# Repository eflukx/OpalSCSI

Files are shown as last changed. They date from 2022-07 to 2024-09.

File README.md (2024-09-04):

# OpalSCSI

Nice, tidy and small BlueSCSI-compatible dongle made to fit classic Macintosh computers. (But probably fits a whole lot more machines sporting a DB-25 SCSI connector!)

## Background

I found an old Macintosh 512k lying around and obviously ~~wanted~~ needed to boot it. It did come with a (rather large) box containing a SCSI drive, but unfortunately/unsurprisingly it did not stand the test of time.. 🥹
So with no apparent way to be able to boot my Mac and no appetite to fiddle with old SCSI drives I stumbled upon the great BlueSCSI project! I loved the project and decided build some hardware to go with the firmware. The design for this is what you find in this repository.
I had all components needed and I did not want to fiddle with loose (dupont) wiring to a bluepill or SCSI cabling or whatever. Therefore decided to build a small dongle board that takes a SD-card and directly plugs into the computer.

## Some nice pictas

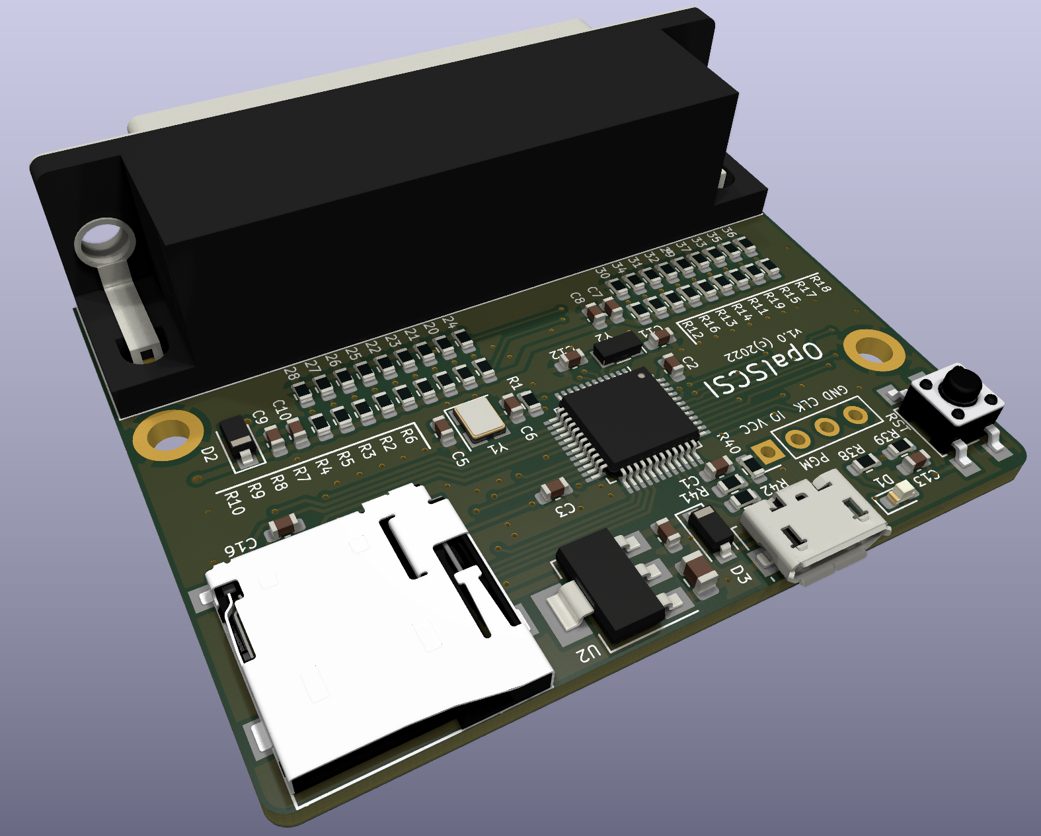
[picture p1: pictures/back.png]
PCB back

<!-- ![PCB bottom_flat](pictures/bottom_flat.png) -->
<!-- ![PCB bottom_perspective](pictures/bottom_perspective.png) -->
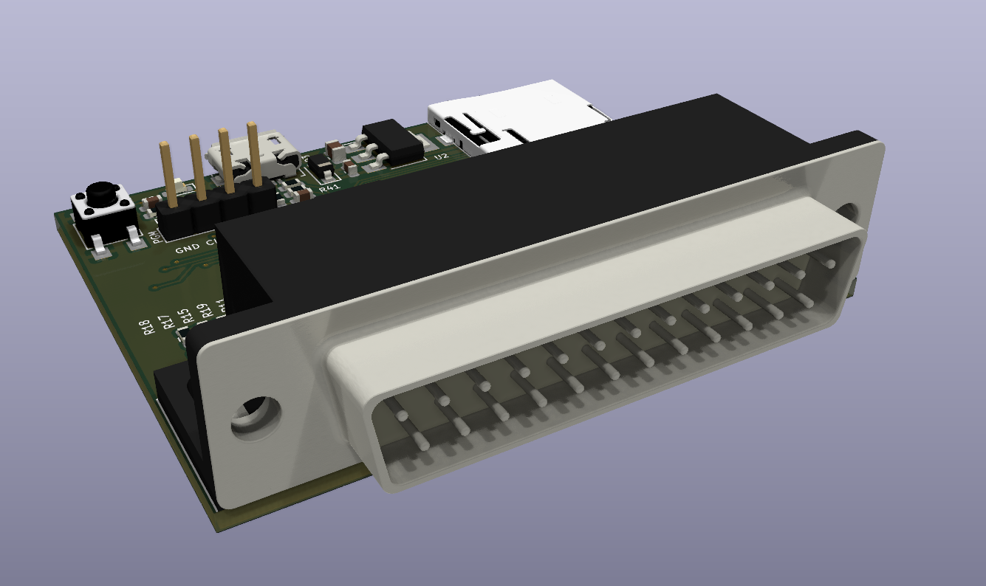
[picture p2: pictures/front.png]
PCB front

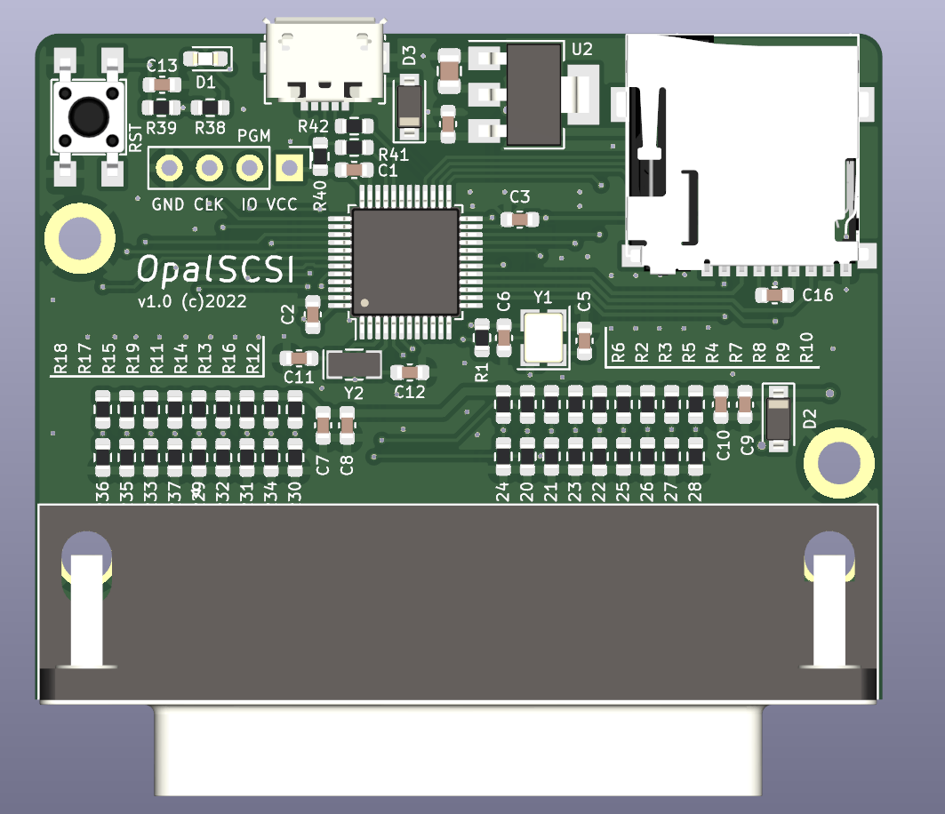
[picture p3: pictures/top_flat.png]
PCB top_flat


## Get one of my boards!

I've had some (5) boards produced and soldered 2 devices together for own use. As I still have some boards lying around, you can get one at shipping cost! 🥳 Just create an issue here with the request, I'll probably pick it up.. :)

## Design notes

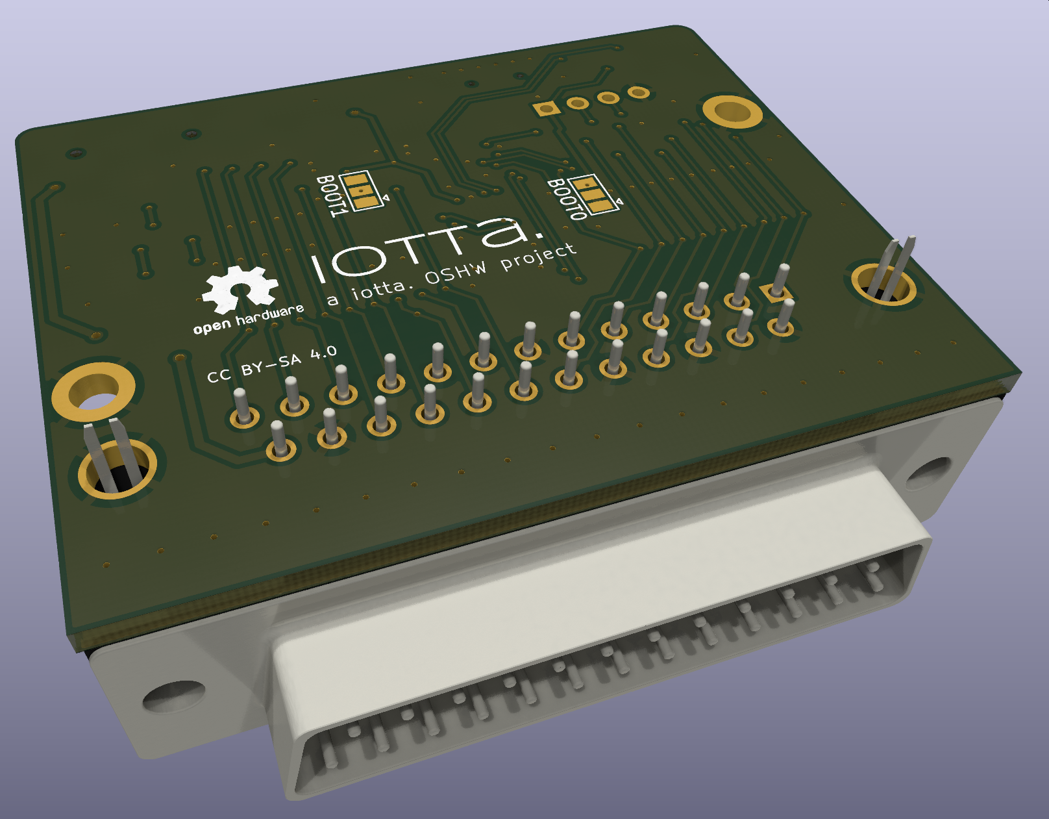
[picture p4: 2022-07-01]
pictures/bottom_perspective.png

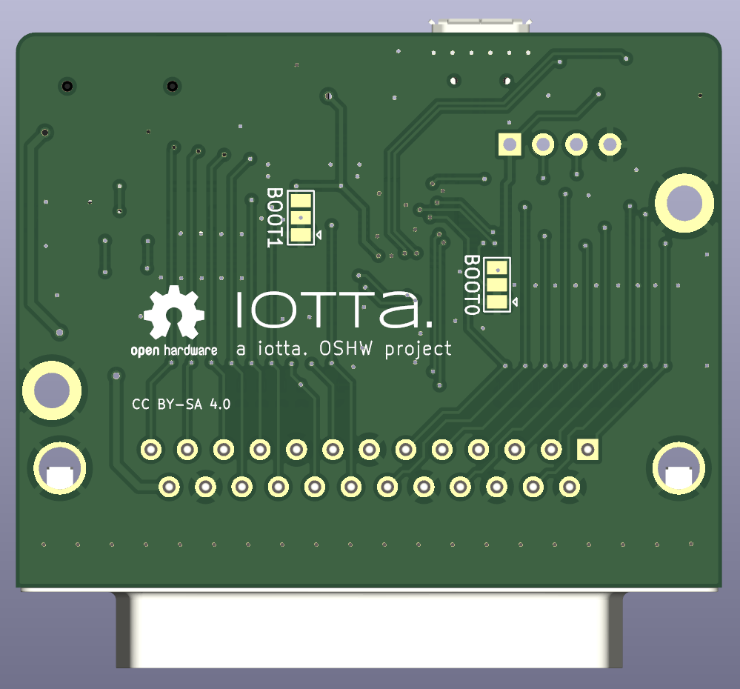
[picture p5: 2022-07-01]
pictures/bottom_flat.png

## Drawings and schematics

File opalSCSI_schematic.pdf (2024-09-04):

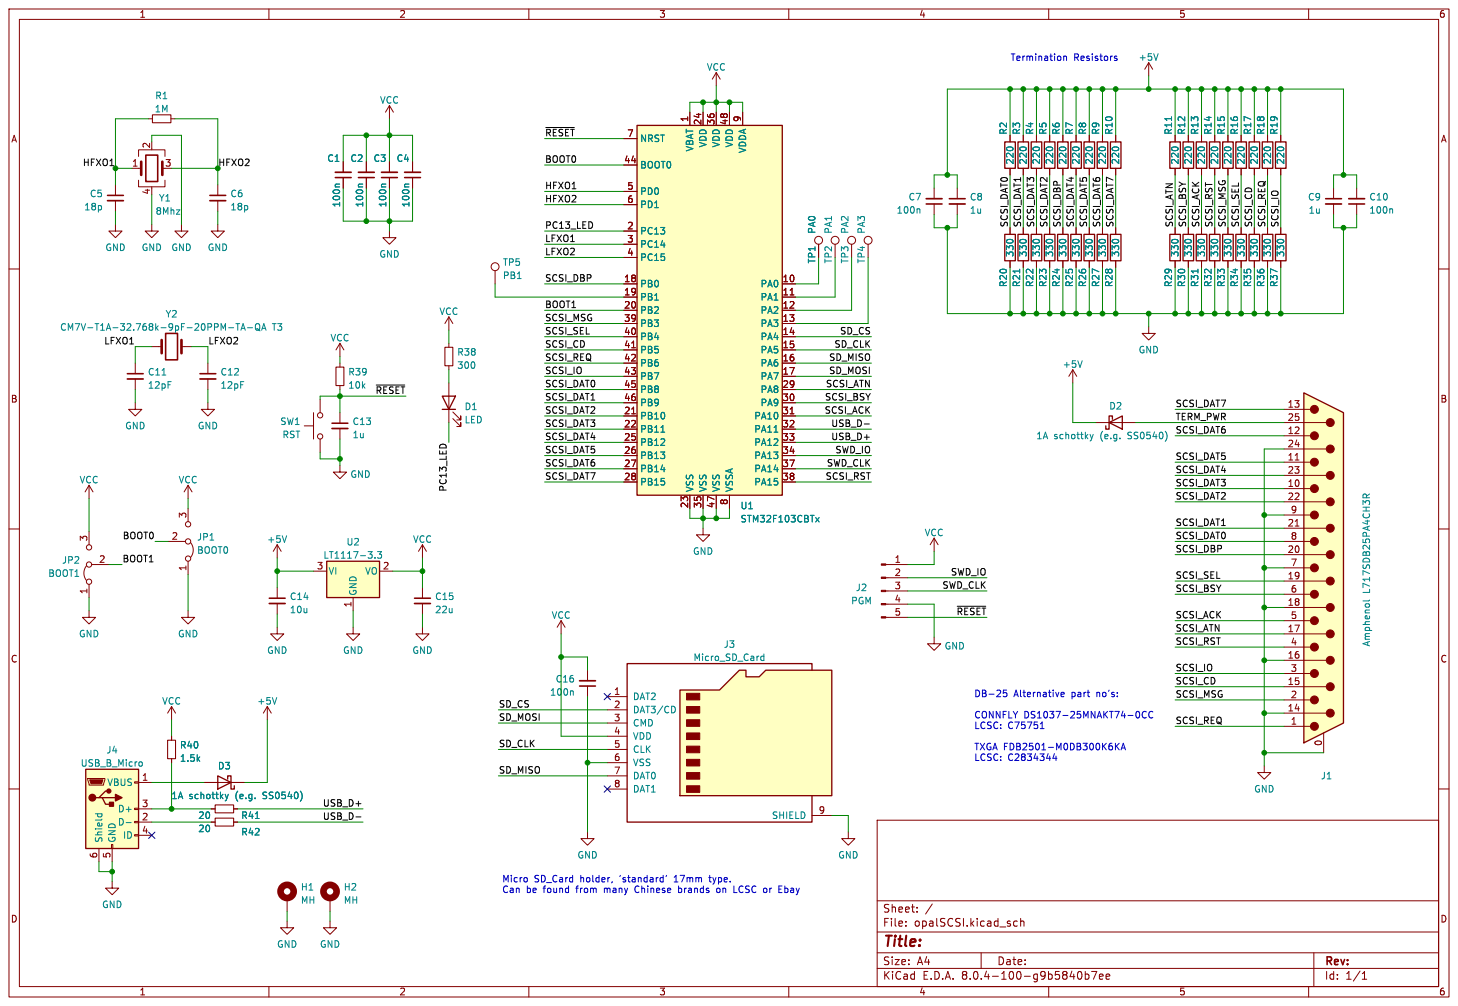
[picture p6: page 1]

1 PA0 10 PA1 11 PA2 12 PA3 13 PA4 14 PA5 15 PA6 16 PA7 17 PB0 18 PB1 19 PC13 2 PB2 20 PB10 21 PB11 22 VSS 23 VDD 24 PB12 25 PB13 26 PB14 27 PB15 28 PA8 29 PC14 3 PA9 30 PA10 31 PA11 32 PA12 33 PA13 34 VSS 35 VDD 36 PA14 37 PA15 38 PB3 39 PC15 4 PB4 40 PB5 41 PB6 42 PB7 43 BOOT0 44 PB8 45 PB9 46 VSS 47 VDD 48 PD0 5 PD1 6 NRST 7 VSSA

Id: 1/1 Title: File: opalSCSI.kicad_sch Sheet: /

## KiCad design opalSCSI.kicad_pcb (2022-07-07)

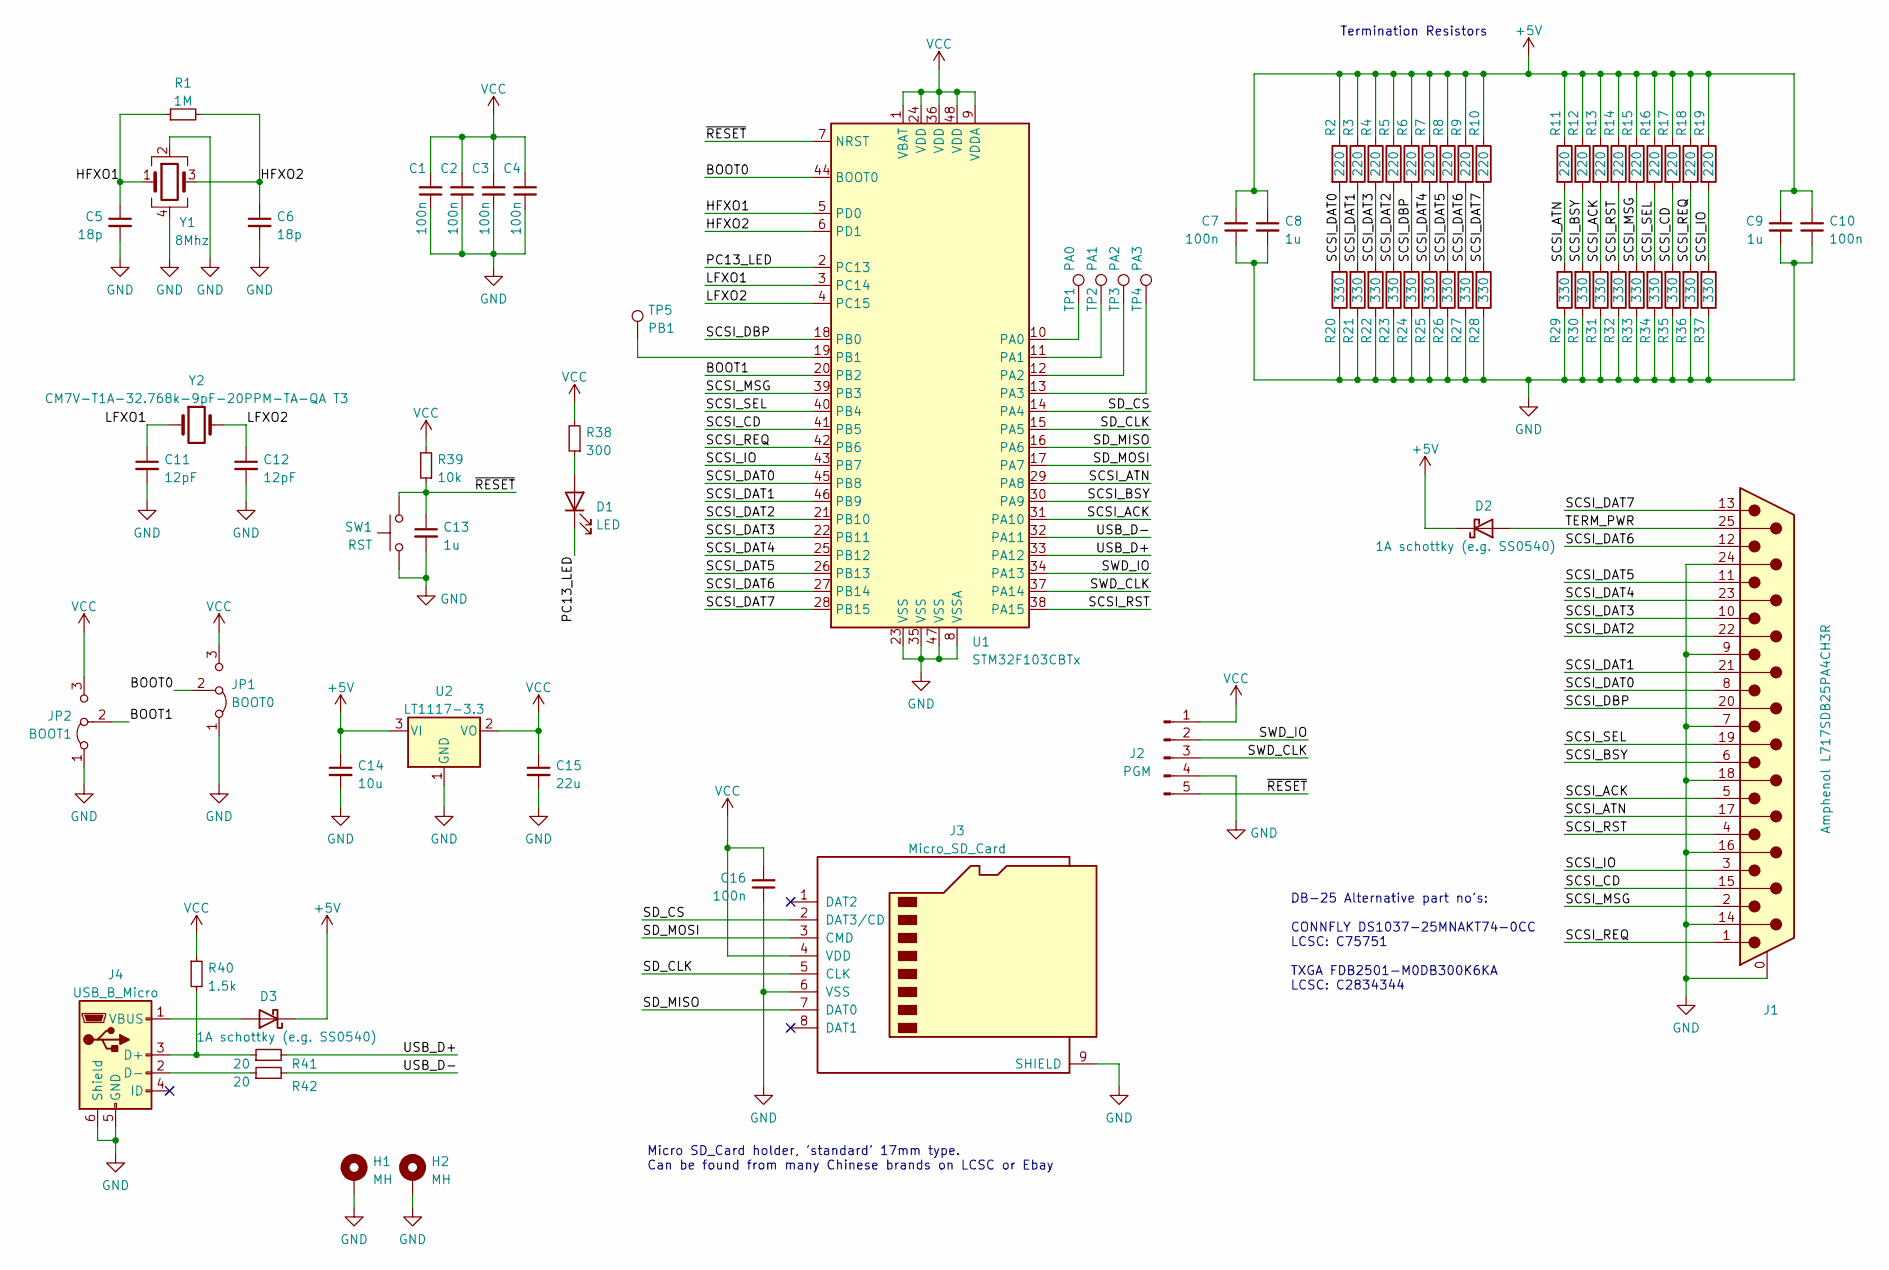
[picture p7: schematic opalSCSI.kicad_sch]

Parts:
C1, C2, C3, C4, C7, C10, C16: 100n; C_0603_1608Metric
C5, C6: 18p; C_0603_1608Metric
C8, C9, C13: 1u; C_0603_1608Metric
C11, C12: 12pF; C_0603_1608Metric
C14: 10u; C_0603_1608Metric
C15: 22u; C_0805_2012Metric
D1: LED; LED_0603_1608Metric_Pad1.05x0.95mm_HandSolder
D2, D3: 1A schottky (e.g. SS0540); D_SOD-123
H1, H2: MH; MountingHole_2.7mm_M2.5_ISO14580_Pad
J1: Amphenol L717SDB25PA4CH3R; DSUB-25_Male_Horizontal_P2.77x2.84mm_EdgePinOffset7.70mm_Ho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
J2: PGM; PinHeader_1x05_P2.54mm_Vertical
J3: Micro_SD_Card; Micro_SD_socket_Ebay
J4: USB_B_Micro; USB_Micro-B_2_Holes
JP1: BOOT0; SolderJumper-3_P1.3mm_Bridged12_Pad1.0x1.5mm
JP2: BOOT1; SolderJumper-3_P1.3mm_Bridged12_Pad1.0x1.5mm
R1: 1M; R_0603_1608Metric
R2, R3, R4, R5, R6, R7, R8, R9, R10, R11, R12, R13, R14, R15, R16, R17, R18, R19: 220; R_0603_1608Metric
R20, R21, R22, R23, R24, R25, R26, R27, R28, R29, R30, R31, R32, R33, R34, R35, R36, R37: 330; R_0603_1608Metric
R38: 300; R_0603_1608Metric
R39: 10k; R_0603_1608Metric
R40: 1.5k; R_0603_1608Metric
R41, R42: 20; R_0603_1608Metric
SW1: RST; SW_SPST_TL3305B
TP1: PA0; TestPoint_Pad_D1.5mm
TP2: PA1; TestPoint_Pad_D1.5mm
TP3: PA2; TestPoint_Pad_D1.5mm
TP4: PA3; TestPoint_Pad_D1.5mm
TP5: PB1; TestPoint_Pad_D1.5mm
U1: STM32F103CBTx; LQFP-48_7x7mm_P0.5mm
U2: LT1117-3.3; SOT-223-3_TabPin2
Y1: 8Mhz; Crystal_SMD_3225-4Pin_3.2x2.5mm
Y2: CM7V-T1A-32.768k-9pF-20PPM-TA-QA T3; Crystal_SMD_MicroCrystal_CC7V-T1A-2Pin_3.2x1.5mm

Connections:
+5V: C7.2, C8.1, C9.1, C10.2, C14.1, D2.1 (K), D3.1 (K), R2.1, R3.1, R4.1, R5.1, R6.1, R7.1, R8.1, R9.1, R10.1, R11.1, R12.1, R13.1, R14.1, R15.1, R16.1, R17.1, R18.1, R19.1, U2.3 (VI)
/BOOT0: JP1.2 (C), U1.44 (BOOT0)
/BOOT1: JP2.2 (C), U1.20 (PB2)
/HFXO1: C5.1, R1.1, U1.5 (PD0), Y1.1
/HFXO2: C6.1, R1.2, U1.6 (PD1), Y1.3
/LFXO1: C11.1, U1.3 (PC14), Y2.1
/LFXO2: C12.1, U1.4 (PC15), Y2.2
/PC13_LED: D1.1 (K), U1.2 (PC13)
/SCSI_ACK: J1.5, R13.2, R31.2, U1.31 (PA10)
/SCSI_ATN: J1.17, R11.2, R29.2, U1.29 (PA8)
/SCSI_BSY: J1.6, R12.2, R30.2, U1.30 (PA9)
/SCSI_CD: J1.15, R17.2, R35.2, U1.41 (PB5)
/SCSI_DAT0: J1.8, R2.2, R20.2, U1.45 (PB8)
/SCSI_DAT1: J1.21, R3.2, R21.2, U1.46 (PB9)
/SCSI_DAT2: J1.22, R5.2, R23.2, U1.21 (PB10)
/SCSI_DAT3: J1.10, R4.2, R22.2, U1.22 (PB11)
/SCSI_DAT4: J1.23, R7.2, R25.2, U1.25 (PB12)
/SCSI_DAT5: J1.11, R8.2, R26.2, U1.26 (PB13)
/SCSI_DAT6: J1.12, R9.2, R27.2, U1.27 (PB14)
/SCSI_DAT7: J1.13, R10.2, R28.2, U1.28 (PB15)
/SCSI_DBP: J1.20, R6.2, R24.2, U1.18 (PB0)
/SCSI_IO: J1.3, R19.2, R37.2, U1.43 (PB7)
/SCSI_MSG: J1.2, R15.2, R33.2, U1.39 (PB3)
/SCSI_REQ: J1.1, R18.2, R36.2, U1.42 (PB6)
/SCSI_RST: J1.4, R14.2, R32.2, U1.38 (PA15)
/SCSI_SEL: J1.19, R16.2, R34.2, U1.40 (PB4)
/SD_CLK: J3.5 (CLK), U1.15 (PA5)
/SD_CS: J3.2 (DAT3/CD), U1.14 (PA4)
/SD_MISO: J3.7 (DAT0), U1.16 (PA6)
/SD_MOSI: J3.3 (CMD), U1.17 (PA7)
/SWD_CLK: J2.3, U1.37 (PA14)
/SWD_IO: J2.2, U1.34 (PA13)
/TERM_PWR: D2.2 (A), J1.25
/USB_D+: R41.2, U1.33 (PA12)
/USB_D-: R42.2, U1.32 (PA11)
/~RESET: C13.1, J2.5, R39.1, SW1.2, U1.7 (NRST)
GND: C1.1, C2.1, C3.1, C4.1, C5.2, C6.2, C7.1, C8.2, C9.2, C10.1, C11.2, C12.2, C13.2, C14.2, C15.2, C16.1, H1.1, H2.1, J1.0 (PAD), J1.7, J1.9, J1.14, J1.16, J1.18, J1.24, J2.4, J3.6 (VSS), J3.9 (SHIELD), J4.5 (GND), J4.6 (Shield), JP1.1 (A), JP2.1 (A), R20.1, R21.1, R22.1, R23.1, R24.1, R25.1, R26.1, R27.1, R28.1, R29.1, R30.1, R31.1, R32.1, R33.1, R34.1, R35.1, R36.1, R37.1, SW1.1, U1.8 (VSSA), U1.23 (VSS), U1.35 (VSS), U1.47 (VSS), U2.1 (GND), Y1.2, Y1.4
unnamed: D1.2 (A), R38.1
unnamed: D3.2 (A), J4.1 (VBUS)
unnamed: J4.2 (D-), R42.1
unnamed: J4.3 (D+), R40.2, R41.1
unnamed: TP1.1, U1.10 (PA0)
unnamed: TP2.1, U1.11 (PA1)
unnamed: TP3.1, U1.12 (PA2)
unnamed: TP4.1, U1.13 (PA3)
unnamed: TP5.1, U1.19 (PB1)
VCC: C1.2, C2.2, C3.2, C4.2, C15.1, C16.2, J2.1, J3.4 (VDD), JP1.3 (B), JP2.3 (B), R38.2, R39.2, R40.1, U1.1 (VBAT), U1.9 (VDDA), U1.24 (VDD), U1.36 (VDD), U1.48 (VDD), U2.2 (VO)

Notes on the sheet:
DB-25 Alternative part no's: CONNFLY DS1037-25MNAKT74-0CC LCSC: C75751 TXGA FDB2501-M0DB300K6KA LCSC: C2834344
Micro SD_Card holder, 'standard' 17mm type. Can be found from many Chinese brands on LCSC or Ebay
Termination Resistors

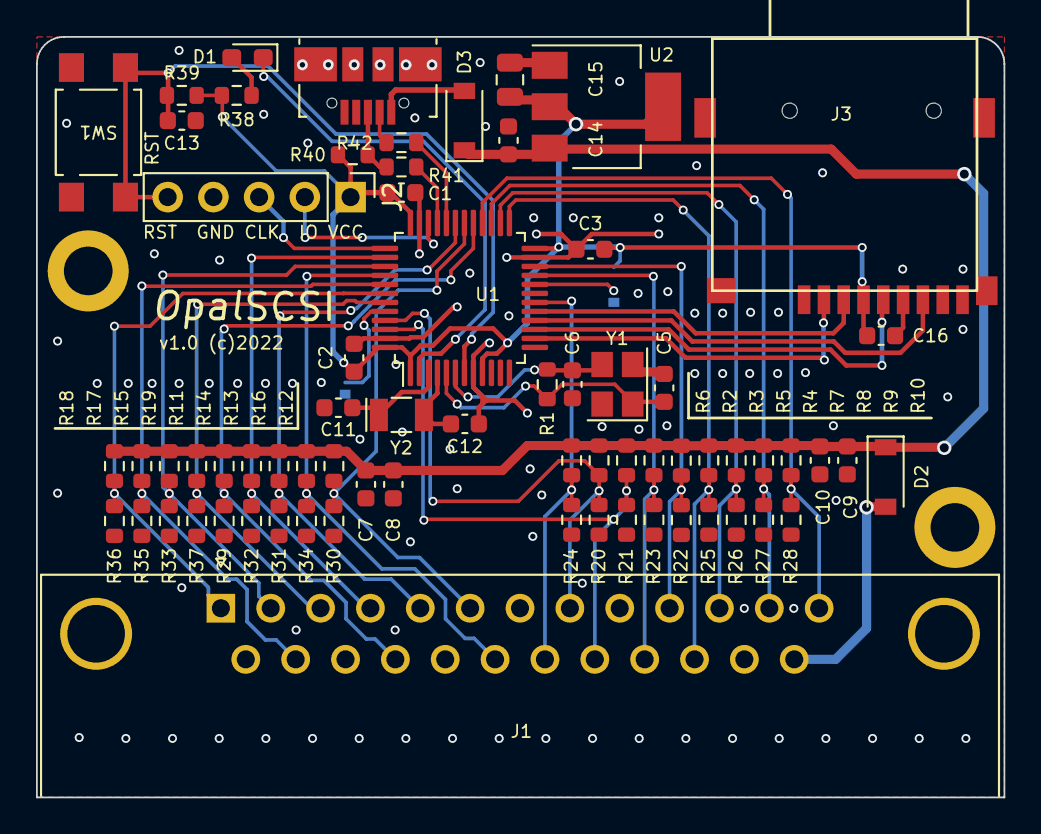
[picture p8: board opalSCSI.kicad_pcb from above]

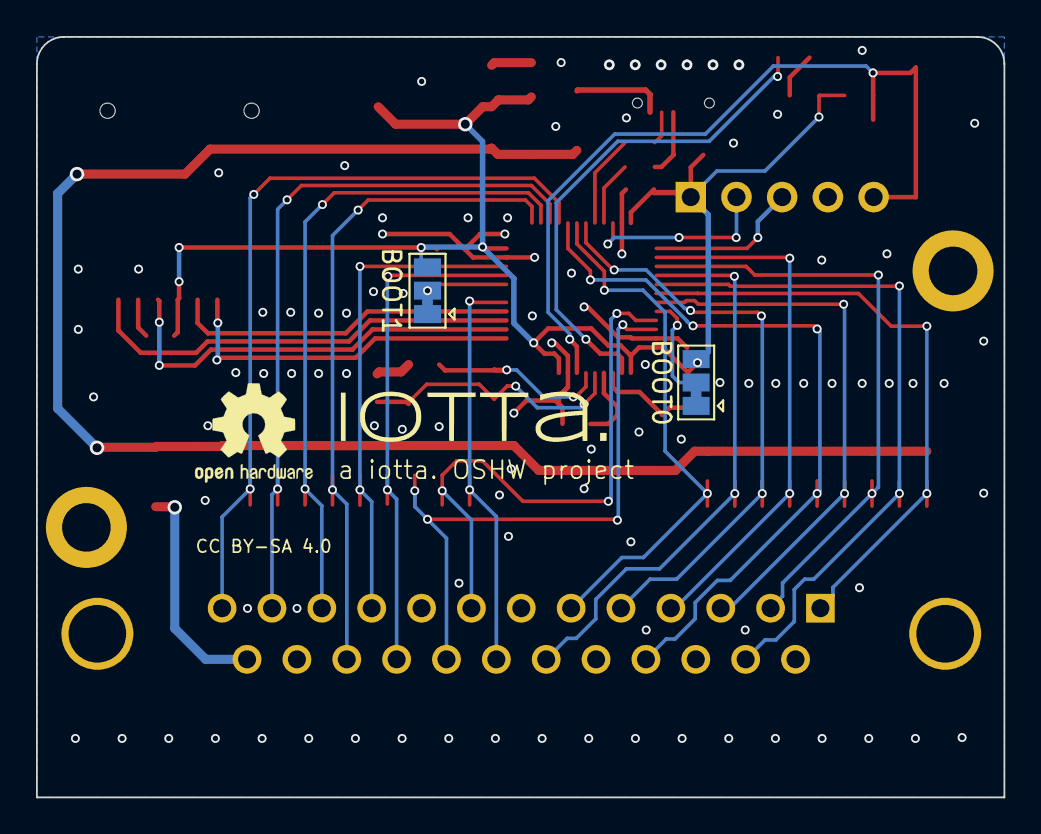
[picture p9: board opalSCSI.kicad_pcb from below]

Board: 2 copper layers, 53.8 x 42.2 mm, 73 parts (2 on the bottom side), 42 nets.

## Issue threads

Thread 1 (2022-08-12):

Eager Beaver

InfraredRidingHood, 2022-08-12:
Hi, I think this is a really cool project and just want to say that If you need somebody to try out the hardware design I would be more than keen.  Can I ask if OpalScsi is going to be hardware only or do you plan on working on the BlueScsi firmware also?

I think your board design ticks all the boxes especially being CC BY-SA 4.0 but the only thing I can suggest is giving it a termination on/off option.

Best wishes,

Stephen.

eflukx, 2022-08-16:
Hi @InfraredRidingHood glad you like the project 👍🏻.

I have a classic Mac that I pulled from the attic and found it was not booting anymore... (external SCSI disk probably died, I don't really know). I looked for a "modern" replacement and found BlueSCSI, so wanted to try that. Only in my opinion the hardware is a bit clunky using a full BluePill on another board... As I had a strip GD32F103's lying around, I decided to design a new board, based on the BlueSCSI hardware (actually a blatant copy.. 😁). The intention is to use the BlueSCSI firmware directly, so this will be a HW-only project. I didn't come around to write up a proper `readme.md` to explain what this is about and just slapped the project files online.. ;)

I actually build two boards today:

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

Will need to try them out with my Mac, keep you posted how that goes..
Btw I have more bare PCB's here, so if your interested will ship you one within Europe @shipping cost.

About the termination.. As there are 18 lines to be terminated i think 18 analog switches will be necessary to make the termination switchable. So that's quite a design change. Anyway this was intended to be plugged directly into the back of a computer so termination is desired in that case. Of course you can always build the design without the termination resistors and have a (fixed) non-terminated device.

InfraredRidingHood, 2022-08-22:
Hi, many thanks for the reply and using the GD32F103 makes a lot of sense and makes the project even better!

Will you be using the https://github.com/androda/F4_BlueSCSI  firmware for this or the original BlueScsi firmware?

As soon as you have this working I will be delighted to make a fork of your HW and share some of my ideas. Thanks for offering me the PCB but since I’m not in Europe so I will just print some off with JLPCB.

Looking forward to your updates.

8waysanta, 2022-08-25:
Hi, have you had time to try OpalSCSI on your Macintosh yet?

eflukx, 2022-08-25:
> Hi, have you had time to try OpalSCSI on your Macintosh yet?

As a matter of fact: 'No' ;)
I was able to flash the firmware onto the device, but as I've been in the middle of a move of our office, I've not been able to test it with the Mac... Expect to come back with results within a few days though.

eflukx, 2022-08-29:
> Hi, have you had time to try OpalSCSI on your Macintosh yet?

Yes, today I finally had some time to try my build. I can confirm it worked like a charm first time! 😄

Earlier I encountered some issues with flashing the firmware onto the device. I used JLink software and [probe-rs](https://probe.rs/), but somehow using these tools did not successfully/correctly flashed the bin file onto the STM32/GD32. So I first flashed the [generic USB bootloader](https://github.com/rogerclarkmelbourne/STM32duino-bootloader/tree/master/binaries) and thereafter I flashed the BlueSCSI firmware using the [BlueSCSI updater](https://github.com/erichelgeson/BlueSCSI-Updater)

Closed 2022-08-30.

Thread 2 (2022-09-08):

LCSC part numbers?

8waysanta, 2022-09-08:
Hi, I was wondering if you could direct me to the LCSC part numbers you used for the Micro SD card holder and the Micro USB connector, many thanks.

eflukx, 2022-09-08:
The SD card reader is pretty _Chinese generic_ 🇨🇳 😸 and can be found from various sources and vendors..

From LCSC the "XUNPU TF-115" [(LCSC# C266620)](https://www.lcsc.com/product-detail/SD-Card-Connectors_XUNPU-TF-115_C266620.html) will fit, as well as the "SOFNG TF-015" [(LCSC# C113206)](https://www.lcsc.com/product-detail/Connector-Card-Sockets_SOFNG-TF-015_C113206.html)

The MicroUSB connector is pretty generic as well (probably even moreso:)) and a lot of different types will fit just fine, for instance this one: [LCSC# C40942](https://lcsc.com/product-detail/USB-Connectors_Jing-Extension-of-the-Electronic-Co-LCSC-micro-5PAll-posts-are-not-guided-Flat-welding-High-temperature_C40942.html)

Closed 2022-09-08.

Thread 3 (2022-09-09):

CM7V-T1A-32.768KHZ-9PF-20PPM-TA-QC

8waysanta, 2022-09-09:
Hi, this is the last but I'm confused about what LCSC part number you have used in place of the 32.768k crystal at "Y2"

CM7V-T1A-32.768KHZ-9PF-20PPM-TA-QC

Thanks again, Stephen.

eflukx, 2022-09-09:
This is just a 1.5x3.2mm 32.768kHz crystal. I think any will do. I have this specific part number in it, as I had these in stock.. :)
Moreover I doubt if the BlueSCSI firmware even uses the low speed crystal... If not, the part doesn't need to be placed at all. I haven't tested that though.. Anyone who can shed light on that?

As for LCSC part no., this one will probably do just fine: [Seiko Epson Q13FC1350000400 (LCSC# C32346)](https://lcsc.com/product-detail/Crystals_Seiko-Epson-Q13FC1350000400_C32346.html)

eflukx, 2022-09-09:
Ps. I'm planning to invest some time to writeup a readme.md and proper BOM. :) (as there seems some interest in this project)

rjocoleman, 2022-09-10:
> Ps. I'm planning to invest some time to writeup a readme.md and proper BOM. :) (as there seems some interest in this project)

Thanks @eflukx - nice work 😀

Closed 2022-09-09.

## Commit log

2022-07-01 Initial commit, V1.0 mostly done :)
    not built and tested for real yet..
    [opalSCSI.kicad_pcb, opalSCSI.kicad_sch]
2022-07-07 Add nReset pin to programming (SWD) header
    [opalSCSI.kicad_pcb, opalSCSI.kicad_sch]
2024-09-04 Why not add a schematics pdf (ony has been 2 years..;)

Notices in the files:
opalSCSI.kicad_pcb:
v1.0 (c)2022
